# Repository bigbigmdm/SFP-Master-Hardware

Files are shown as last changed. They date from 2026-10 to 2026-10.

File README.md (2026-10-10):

# SFP-Master-Hardware

**SFP-Master** is a free, cross-platform program for programming optical SFP modules. It allows you to read, write, and save SFP module data on a computer.
Software part of **SFP-Master** project is [here](https://github.com/bigbigmdm/SFP-Master). The description of the hardware is provided here.

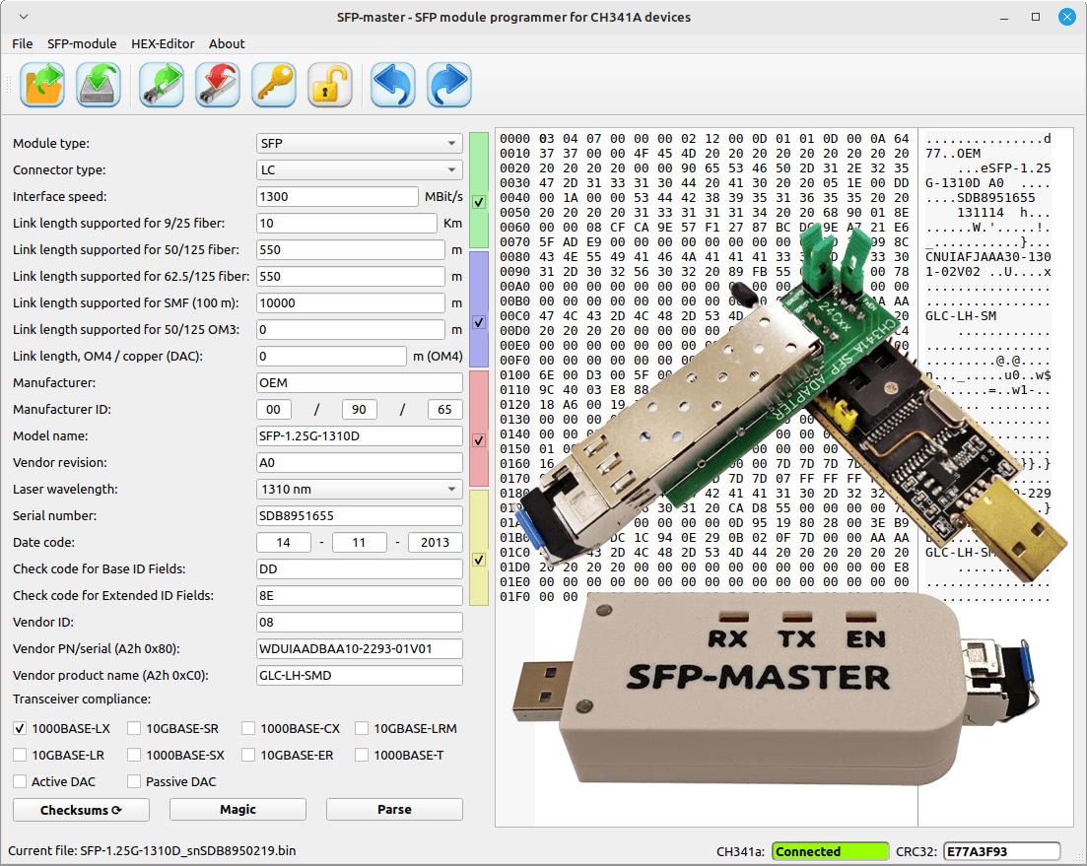
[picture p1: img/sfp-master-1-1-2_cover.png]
Cover image


The hardware part of SFP-Master can be assembling in two variants:
* [Adapter](#adapter) for very popular low cost CH341 programmer device.
* [SFP-Master device](#sfp-master-device)

## Adapter

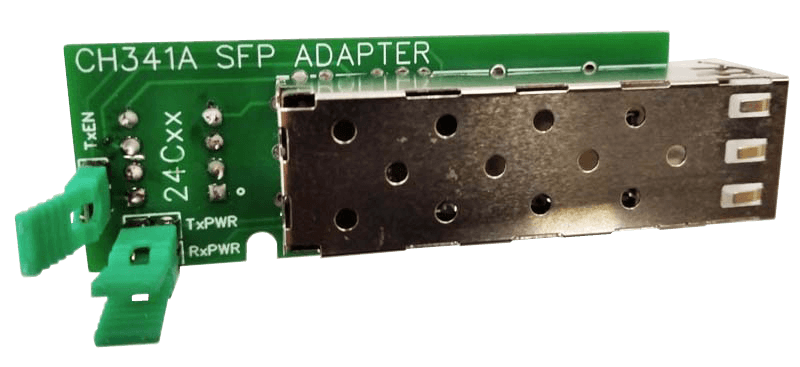
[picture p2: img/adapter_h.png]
Adapter


This adapter must be connected to the section of the CH341 programmer's ZIF socket marked with the "24xx" symbols. At the same time, the ZIF socket lever must fit into the oval cutout on the adapter board.

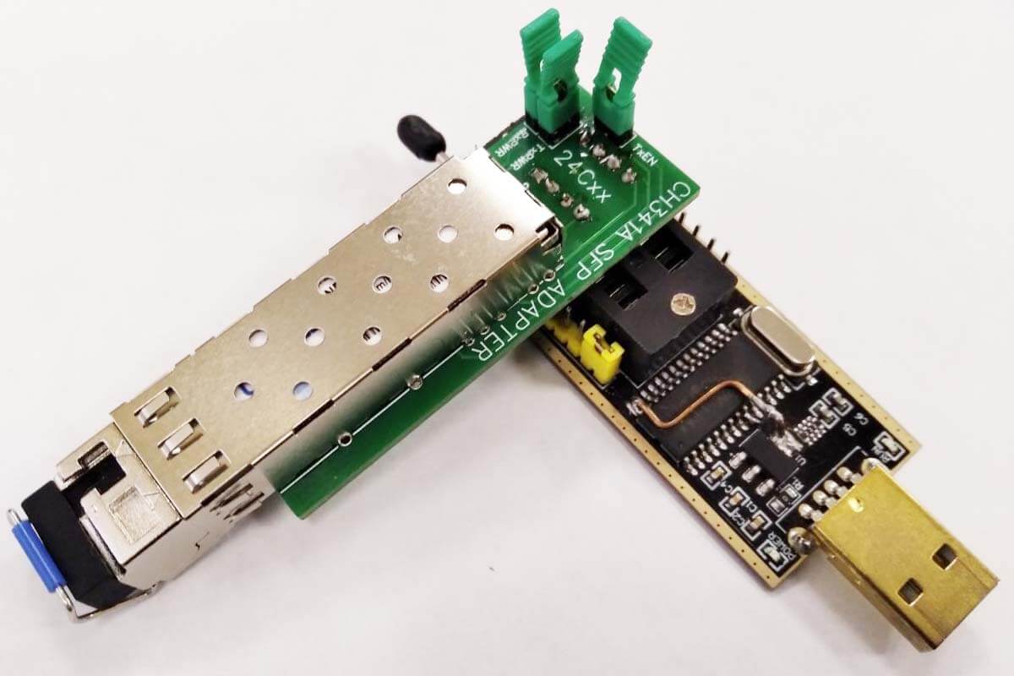
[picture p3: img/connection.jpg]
Connection


### Schematic diagram

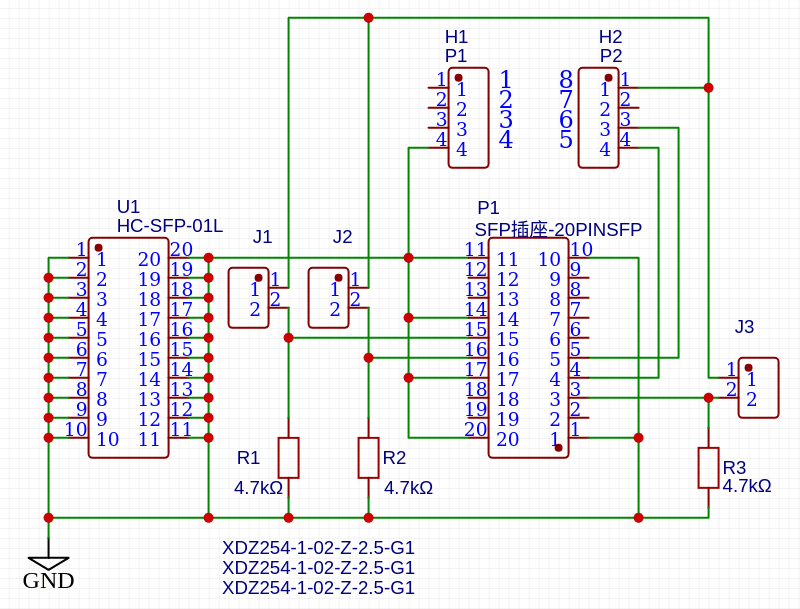
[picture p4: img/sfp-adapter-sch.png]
Adapter schematic


Jumpers J1 to J3 (TxPWR, RxPWR, TxEN) must be installed initially. They are used to supply power to the SFP module. If you want to program a module with hardware write protection, remove one of the jumpers and try to program the module. If it fails, remove the other jumper and repeat the operation.

Bill of material:

| ID  |  Name | Footprint | Designator | Quantity | LCSC link |
|:---:| :--- | :--- | :--- |  :---: | :---: |
|  1  |  P1 | H1 | PZ254V-11-04P | 1 | [Link](https://www.lcsc.com/product-detail/C2691448.html?s_z=n_q_PZ-254V) |
|  2  |  P2 | H2 | PZ254V-11-04P | 1 | [Link](https://www.lcsc.com/product-detail/C2691448.html?s_z=n_q_PZ-254V) |
|  3  | XDZ254-1-02-Z-2.5-G1 | J1,J2,J3  | PZ254V-11-02P | 3 | [Link](https://www.lcsc.com/product-detail/C492401.html?s_z=n_q_l_HDR-TH_4P-P2.54-V-M) |
|  4  | SFP插座-20PINSFP 	 | P1 | KSP20LG154 | 1 | [Link](https://www.lcsc.com/product-detail/C404108.html?s_z=n_q_t_SFP) |
|  5  | HC-SFP-01L | U1 | HCSFP01 | 1 | [Link](https://www.lcsc.com/product-detail/C42418478.html?s_z=n_q_t_SFP) |
|  6  | 4.7kΩ	 | R1,R2,R3  | R0805 | 3 | [Link](https://www.lcsc.com/product-detail/C19696946.html?s_z=n_q_t_resistor%2520smd) |

### Printed circuit board

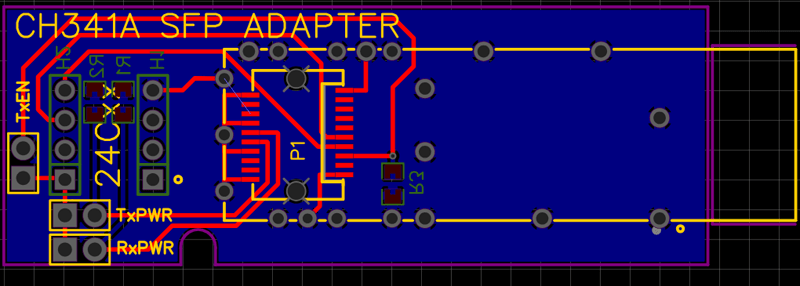
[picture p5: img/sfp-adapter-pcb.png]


You can download the Gerber file to order this PCB [here](https://github.com/bigbigmdm/SFP-Master-Hardware/blob/main/gerber/Gerber_CH341A_SFP_ADAPTER_PCB_CH341A_SFP_ADAPTER_2024-11-22.zip).

You can see or downloading Kicad project by [Arend Jan Kramer](https://github.com/ArendJanKramer) [here](https://github.com/bigbigmdm/SFP-Master-Hardware/blob/main/kicad-adapter).

You can view this project in OSHWLab (EasyEDA) [here](https://oshwlab.com/einkreader/ch341a_sfp_adapter)

## SFP-master device

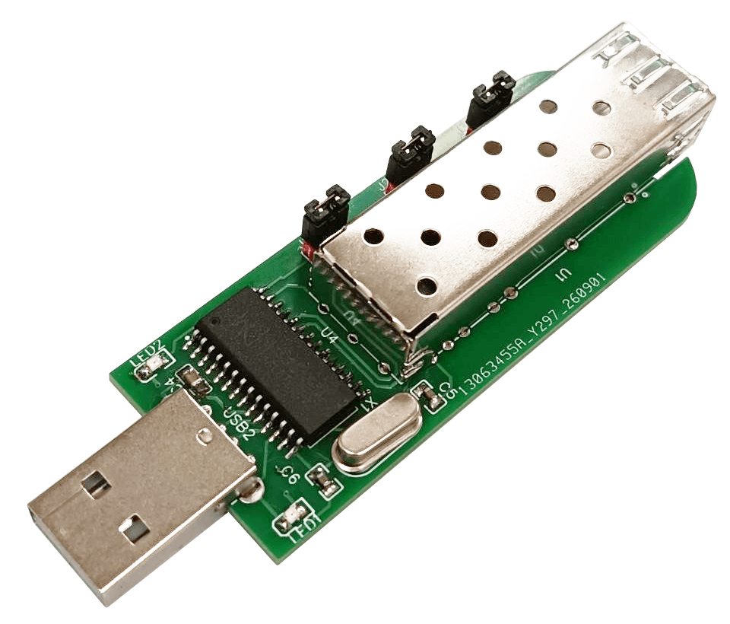
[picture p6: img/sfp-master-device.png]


### Schematic diagram

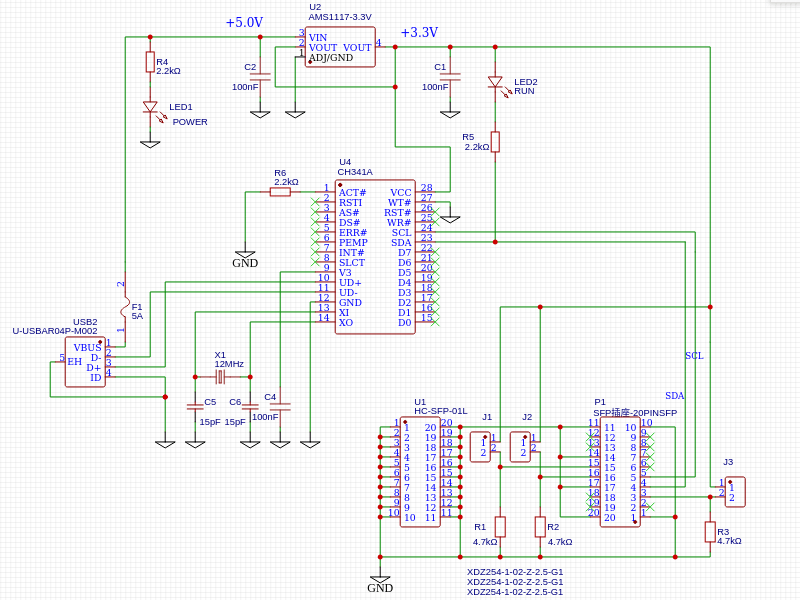
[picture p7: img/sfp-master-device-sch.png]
SFP-Master schematic


The `SFP-master` device utilized the `CH341A` USB-to-I2C converter chip manufactured by Nanjing Qinheng Microelectronics Co., Ltd.,
connected according to the standard circuit configuration.
Jumpers J1 to J3 (TxPWR, RxPWR, TxEN) must be installed initially. They are used to supply power to the SFP module. 
If you want to programm a module with hardware write protection, remove one of the jumpers and try to programm the module. 
If it fails, remove the other jumper and repeat the operation.

Bill of material:

| ID  |  Name | Footprint | Designator | Quantity | LCSC link |
|:---:| :--- | :--- | :--- |  :---: | :---: |
|  1  | 100nF | C1,C2,C4  | C0805 | 3 | [Link](https://www.lcsc.com/product-detail/C344180.html?s_z=s_q_t_100NF%2520C0805) |
|  2  | 15pF | C5,C6 | C0805 | 2 | [Link](https://www.lcsc.com/product-detail/C2171919.html?s_z=n_q_t_15PF%2520C0805) |
|  3  | 5A | F1 | F0805 | 1 | [Link](https://www.lcsc.com/product-detail/C3159342.html) |
|  4  | XDZ254-1-02-Z-2.5-G1 | J1,J2,J3  | PZ254V-11-02P | 3 | [Link](https://www.lcsc.com/product-detail/C492401.html?s_z=n_q_l_HDR-TH_4P-P2.54-V-M) |
|  5  | SFP插座-20PINSFP 	 | P1 | KSP20LG154 | 1 | [Link](https://www.lcsc.com/product-detail/C404108.html?s_z=n_q_t_SFP) |
|  6  | 4.7kΩ	 | R1,R2,R3  | R0805 | 3 | [Link](https://www.lcsc.com/product-detail/C19696946.html?s_z=n_q_t_resistor%2520smd) |
|  7  | HC-SFP-01L | U1 | HCSFP01 | 1 | [Link](https://www.lcsc.com/product-detail/C42418478.html?s_z=n_q_t_SFP) |
|  8  | AMS1117-3.3V | U2 | SOT-223-4_L6.5-W3.5-P2.30-LS7.0-BR | 1 | [Link](https://www.lcsc.com/product-detail/C20611856.html) |
|  9  | U-USBAR04P-M002 | USB2 | USB-A-TH_U-USBAR04P-M002| 1 | [Link](https://www.lcsc.com/product-detail/C404965.html) |
| 10  | POWER | LED1 | LED0805 | 1 | [Link](https://www.lcsc.com/product-detail/C19171391.html) |
| 11  | RUN | LED2 | LED0805 | 1 | [Link](https://www.lcsc.com/product-detail/C19171391.html) |
| 12  | 12MHz | X1 | HC-49US_L11.5-W4.5-P4.88 | 1 | [Link](https://www.lcsc.com/product-detail/C7471636.html) |
| 13  | 2.2kΩ | R5,R6,R4  | R0805 | 3 | [Link](https://www.lcsc.com/product-detail/C2907234.html) |
| 14  | CH341A | U4 | SOIC-28_L17.9-W7.5-P1.27-LS10.3-BL | 1 | [Link](https://www.lcsc.com/product-detail/C13517.html) |

### Printed circuit board

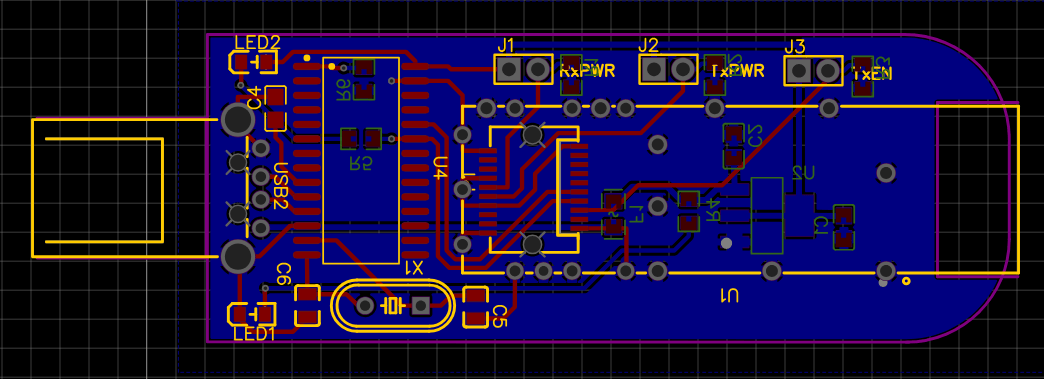
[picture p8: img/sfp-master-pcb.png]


You can download the Gerber file to order this PCB [here](https://github.com/bigbigmdm/SFP-Master-Hardware/blob/main/gerber/Gerber_SFP-Master_PCB_SFP-Master_2_2026-04-07.zip).

You can view this project in OSHWLab (EasyEDA) [here](https://oshwlab.com/einkreader/sfp-master)

To be continued ...

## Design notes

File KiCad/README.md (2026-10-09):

# KiCad files

| KiCad render | Assembled product |
|:---:|:---:|
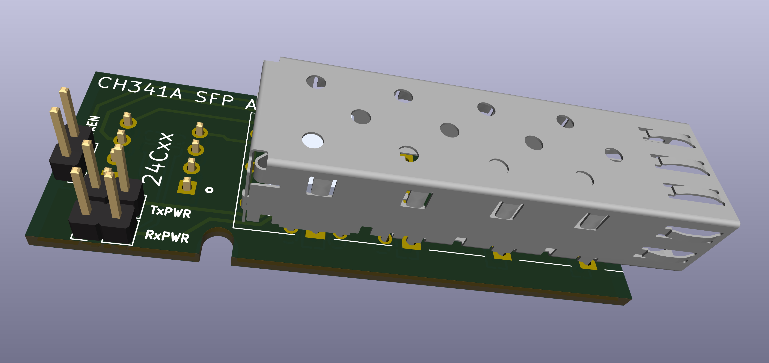
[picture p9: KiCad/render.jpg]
KiCad render
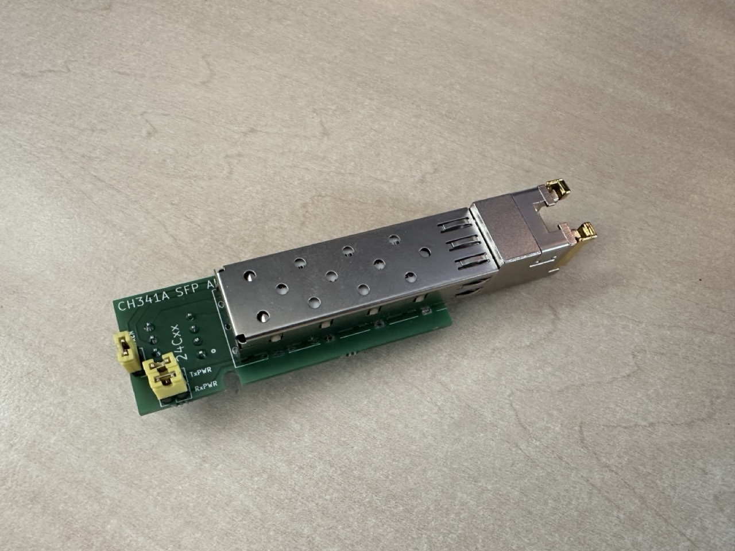
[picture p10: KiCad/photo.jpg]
Assembled product
|  |  |

## BOM

| Molex  | 74441-0001 |
|---|---|
| Molex  | 74737-0009 |

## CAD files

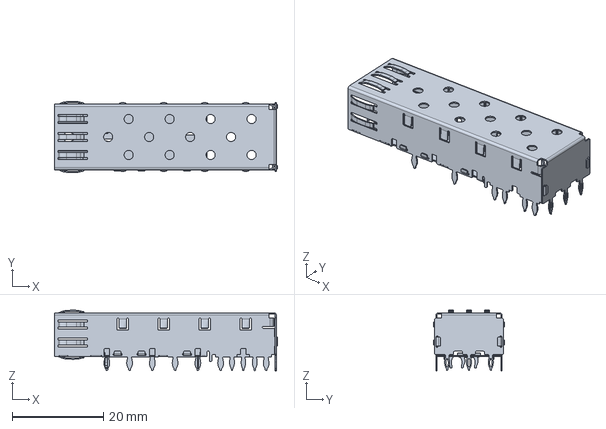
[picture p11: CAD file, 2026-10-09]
KiCad/74737-0009.stp
49.0 x 15.6 x 13.3 mm

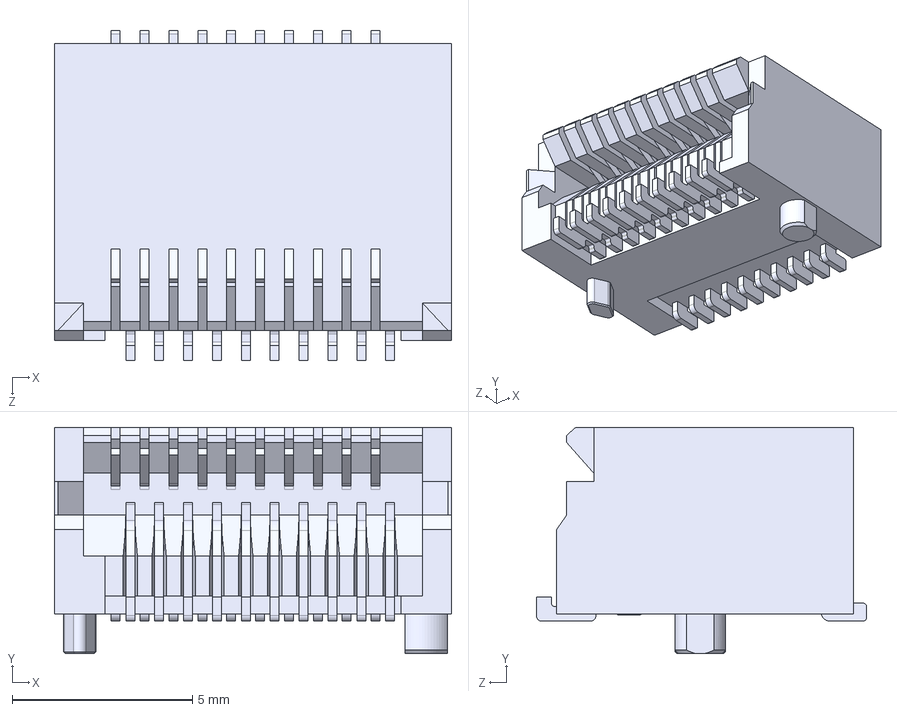
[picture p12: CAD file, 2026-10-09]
KiCad/137198.step
11.0 x 6.27 x 9.15 mm

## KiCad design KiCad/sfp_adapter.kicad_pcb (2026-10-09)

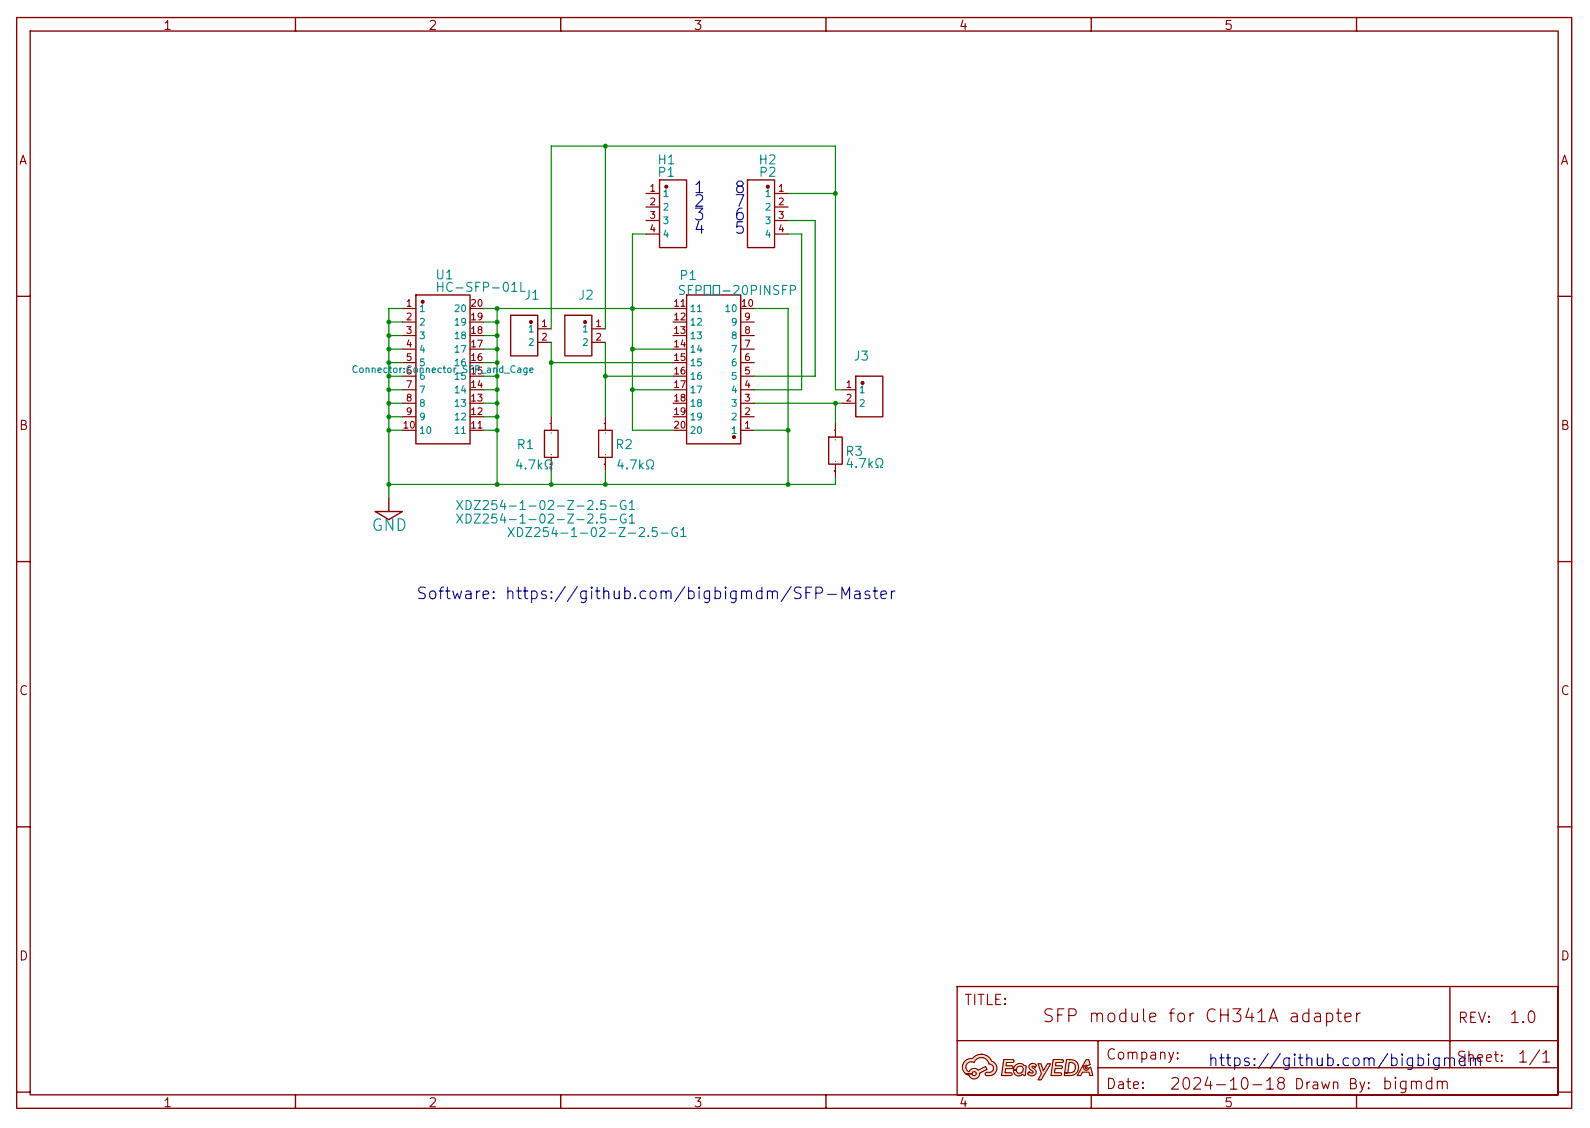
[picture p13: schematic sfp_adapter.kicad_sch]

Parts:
A1: A; Manufacturer Part ?
H1: P1; PinHeader_1x04_P2.54mm_Vertical; Manufacturer Part PZ254V-11-04P
H2: P2; PinHeader_1x04_P2.54mm_Vertical; Manufacturer Part PZ254V-11-04P
J1, J2, J3: XDZ254-1-02-Z-2.5-G1; PinHeader_1x02_P2.54mm_Vertical; Manufacturer Part XDZ254-1-02-Z-2.5-G1
P1: SFP插座-20PINSFP; CONN-SMD_SFP-20PIN; Manufacturer Part SFP插座-20PINSFP
R1, R2, R3: 4.7kΩ; R_0805_2012Metric; Manufacturer Part 0805 ±1% 4K7
U1: HC-SFP-01L; Connector_SFP_and_Cage; Manufacturer Part HC-SFP-01L

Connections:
GND: H1.4 (4_4), P1.1, P1.10, P1.11, P1.14, P1.17, P1.20, R1.1, R2.1, R3.1, U1.1, U1.2, U1.3, U1.4, U1.5, U1.6, U1.7, U1.8, U1.9, U1.10, U1.11, U1.12, U1.13, U1.14, U1.15, U1.16, U1.17, U1.18, U1.19, U1.20
unnamed: H2.1, J1.1, J2.1, J3.1
unnamed: H2.3, P1.5
unnamed: H2.4, P1.4
unnamed: J1.2, P1.15, R1.2
unnamed: J2.2, P1.16, R2.2
unnamed: J3.2, P1.3, R3.2

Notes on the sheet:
Software: https://github.com/bigbigmdm/SFP-Master
https://github.com/bigbigmdm

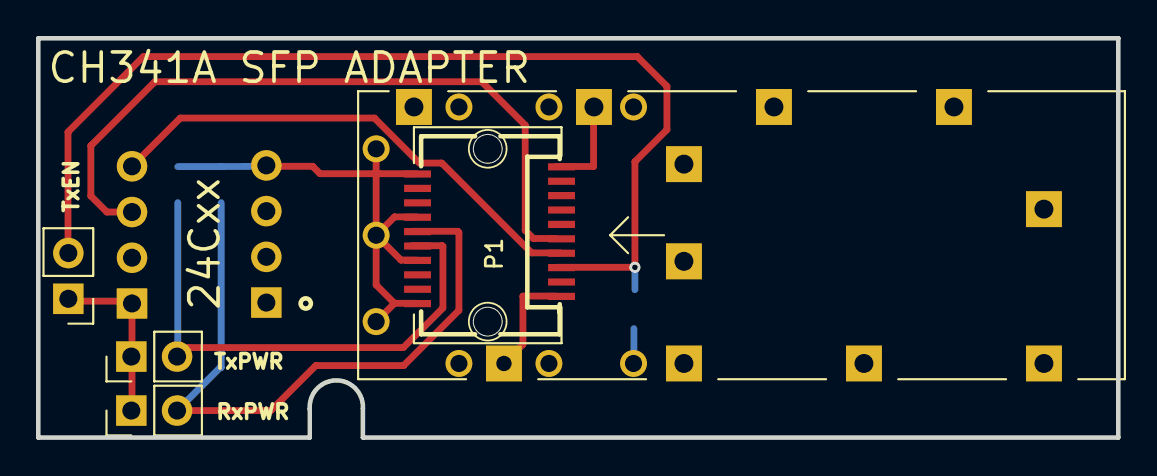
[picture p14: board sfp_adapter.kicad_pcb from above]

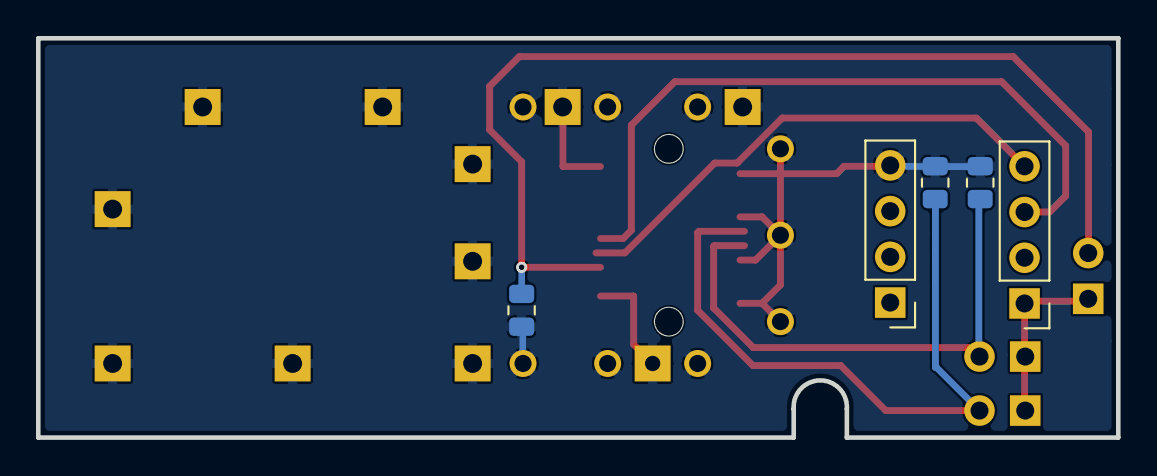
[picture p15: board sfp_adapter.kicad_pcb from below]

Board: 2 copper layers, 60.0 x 22.2 mm, 10 parts (5 on the bottom side), 7 nets.

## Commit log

2026-10-09 Add adapter schematic image to README
2026-10-09 Fix link case sensitivity for SFP-Master device
    Corrected link formatting for SFP-Master device in README.
2026-10-09 Add KiCad files
    [137198.step, 74737-0009.stp, sfp_adapter.kicad_pcb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]
2026-10-09 Add PCB section to README
    Added section about printed circuit board with image.
2026-10-09 Add bill of materials to README
    Added a bill of materials section to the README.
2026-10-09 Update bill of materials with LCSC links
    Added LCSC links to the bill of materials for components.
2026-10-09 Revise bill of materials in README
    Updated bill of materials with new footprints and designators.
2026-10-09 Enhance README with SFP-master details
    Added schematic diagram and bill of materials for SFP-master device.
2026-10-09 Fix links and add components to bill of materials
2026-10-10 Add PCB details to README
    Added PCB section with image and download links.
2026-10-12 Add 3D-print case section to README
    Added a section for 3D-print case details including IDs, descriptions, STL, and FreeCad links.
2026-10-15 Add PCB image to README
    Added an additional PCB image to the README.
